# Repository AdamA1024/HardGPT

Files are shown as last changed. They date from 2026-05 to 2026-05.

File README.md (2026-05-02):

# HardGPT

A character-level GPT running entirely on a TI MSPM0G3507 Cortex-M0+ — no host
PC, no network, no accelerator. Press **Generate** and the chip composes
fake-Shakespeare one character at a time on a 16x2 LCD, beeping at the start
and end. Three buttons, three LEDs, an active buzzer, and a dollar's worth of
flash.

The model is a 3-layer transformer (4 heads, 48 embedding dims, block size 48,
65-character vocab) trained on the tiny-shakespeare corpus. Weights are int8
symmetric per-output-channel quantized so the whole network fits in flash, and
the KV cache is also int8 to keep SRAM use sane during generation.

<p align="center">
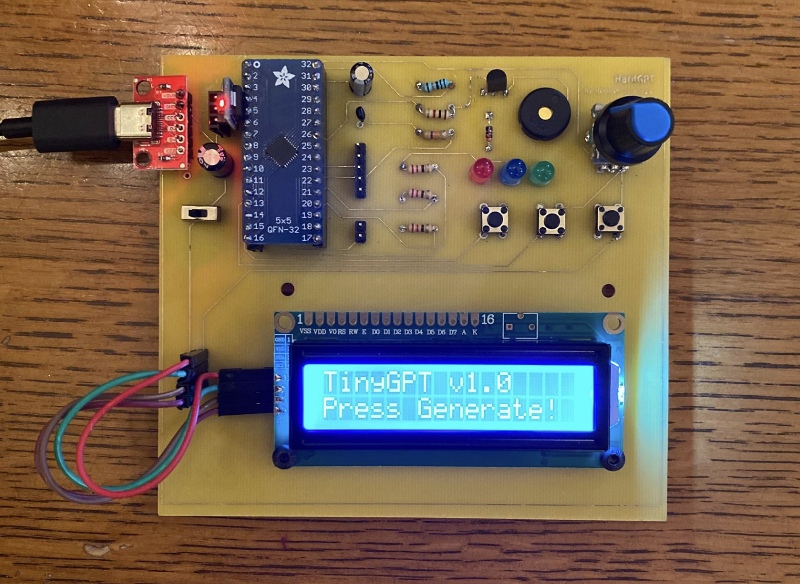
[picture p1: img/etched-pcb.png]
Etched PCB
  
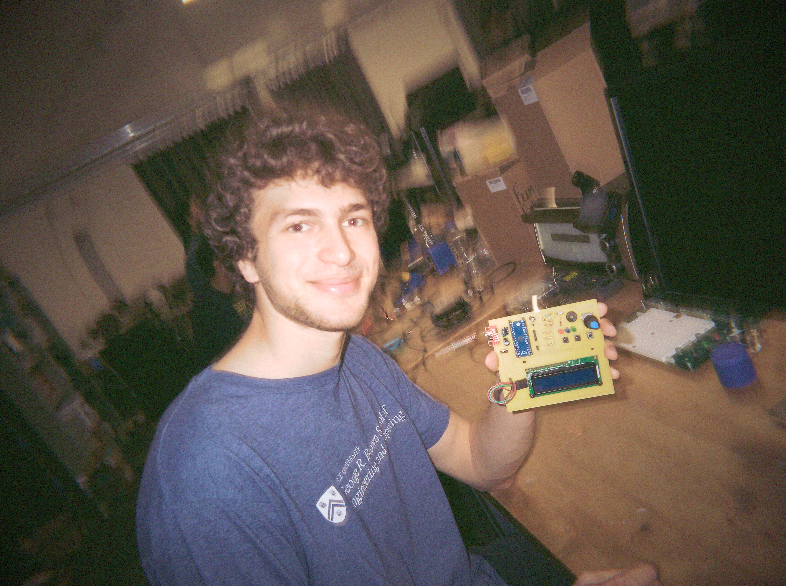
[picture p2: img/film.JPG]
Film
  
</p>

## Repo layout

```
HardGPT/
├── main.c              firmware entry point — UI, transformer inference loop
├── lcd.h               header-only HD44780-via-PCF8574 driver
├── weights.h           int8 weights + vocab, generated by training/export
├── hardgpt.syscfg      sysconfig project: clocks, GPIO, I2C
├── targetConfigs/      CCS debug configs for the launchpad
├── pcb/                kicad project for the board
├── img/                photos used in this readme
└── training/           offline training + weight export pipeline
```

## How it works

The whole firmware lives in a single `main.c` because the model is small
enough that splitting it would just add ceremony. Walking through it top to
bottom:

### Activation and KV-cache buffers

A handful of static SRAM arrays hold the activations of one token at a time:

- `x`, `x_residual`, `x_norm` — the running embedding vector (length `N_EMBD`)
- `qkv` — the combined query/key/value projection (length `3 * N_EMBD`)
- `ffn_hidden` — the 4×-wide MLP hidden state
- `logits` — the output distribution over the 65-character vocabulary
- `x_q` — int8 scratch buffer used whenever we need to quantize an activation

The KV cache is `int8 kv_cache[N_LAYER][BLOCK_SIZE][2 * N_EMBD]` with
`float kv_scales[...]` alongside, so each cached K and V vector keeps its own
quantization scale. Storing it as int8 cuts the cache footprint by ~4× versus
float.

### Math primitives

Everything that touches the hot path uses fast, approximate floats:

- `quantize_vec` — symmetric int8 quantization of a vector with one shared
  scale, used to feed activations into the int8 matmul.
- `matvec_i8i8_pc` — the workhorse. Multiplies an int8 weight matrix (with
  per-row scales) against an int8 activation vector (with one scale) and
  accumulates into int32, then converts to float at the end. This single
  routine handles QKV projection, attention output projection, and both MLP
  matmuls.
- `fast_invsqrt` — the famous Quake `0x5f3759df` trick + one Newton-Raphson
  step. Used by both LayerNorm and the attention scaling factor.
- `fast_expf` — Schraudolph's bit-hack exp. Wildly inaccurate in absolute
  terms but plenty good once softmax normalizes.
- `fast_tanhf` — a Padé approximation, ~1 % error in [-3, 3], used inside
  GELU.
- `layernorm`, `gelu`, `softmax` — built on top of the above.

### The transformer block

`Layer` is just a struct of pointers into `weights.h` so the block code can
work with `L->attn_qkv_w` etc. instead of macro-mangled names.
`init_layers()` wires layer 0/1/2 once at boot.

`block_forward(layer_i, pos)` does one transformer block:

1. Save the residual, layernorm into `x_norm`.
2. Quantize `x_norm`, run the QKV matmul, split into `q`, `k`, `v`.
3. Quantize the new `k` and `v` and store them at `kv_cache[layer_i][pos]`.
4. For each head: dot the head's `q` against every cached `k_t` (dequantizing
   on the fly), scale by `1/sqrt(head_dim)`, softmax, then accumulate the
   weighted sum of cached `v_t`.
5. Quantize the attention output, run the output projection, add the residual.
6. LayerNorm again, run the 4× MLP with GELU, project back, add the residual.

`forward(token_id, pos)` adds the token + position embeddings, calls
`block_forward` for each layer, runs the final LayerNorm, and reuses the
embedding table as the LM head (weight tying) to produce `logits`.

`slide_kv_cache()` shifts the cache left by one when generation runs past
`BLOCK_SIZE`, so the model always sees the most recent `BLOCK_SIZE - 1`
tokens.

### Sampling

Two sampling modes:

- `sample_argmax` — greedy.
- `sample_temp(temperature)` — divide logits by temperature, softmax, draw
  from the distribution using a small linear-congruential RNG.

The probability of the chosen token is stashed in `last_token_prob` so the
"confidence" LED can light up when the model is sure.

### LCD typewriter

`LcdView` holds a 2-row shadow buffer plus the current `(row, col)`. As
characters arrive, `lcd_view_putchar` writes them straight to the LCD and
mirrors them into the shadow buffer. When the cursor walks off row 1, we
copy row 1 up to row 0, blank row 1, and continue — the result is a smooth
typewriter that scrolls upward indefinitely.

### UI / main loop

Boot sequence:

1. `SYSCFG_DL_init()` brings up clocks/GPIO/I2C from sysconfig.
2. `init_layers()` wires the layer pointer table.
3. `lcd_init()` runs the HD44780 wake-up dance and switches it into 4-bit mode.
4. A short buzzer beep confirms power-on.

Then the forever loop:

- **Idle** screen says `HardGPT v1.0 / Press Generate!`. The buttons let you
  cycle through seeds (`Random`, `KING`, `ROMEO`, `LORD`, `HENRY`) or peek at
  the temperature.
- **Generate**: beep, light up the "running" LED, clear the KV cache, print
  the seed name as a cosmetic prefix, then loop:
    - run `forward(token, pos)`
    - sample the next token
    - print it through the LCD typewriter
    - toggle LED 2 (one tick per token), light LED 3 if `last_token_prob > 0.5`
    - increment `pos`; slide the KV cache if we hit `BLOCK_SIZE`
    - bail out early if Generate is pressed again (interrupts the run)
- After 300 tokens (or interrupt), beep twice, wait, and return to idle.

## Hardware

| Peripheral | Pin | Purpose |
|---|---|---|
| 16x2 LCD | I2C0 — SDA on PA0, SCL on PA1 | shows generated text, scrolls upward (PCF8574 backpack)|
| Generate btn  | PA5  (input, internal pull-up) | start / interrupt generation |
| Temp btn | PA7  (input, internal pull-up) | preview the sampling temperature |
| Seed btn | PA8  (input, internal pull-up) | cycle the seed character / name |
| LED 1 | PA12 (output) | "running" — lit during generation |
| LED 2 | PA17 (output) | toggles once per generated token |
| LED 3 | PA18 (output) | lit when sampled token's probability > 0.5 |
| Buzzer | PA22 (output, NPN switch) | boot beep + start/end-of-generation cue |
| SWD | SWCLK on PA20, SWDIO on PA19 | flashing / debug from CCS |

Pin assignments live in `hardgpt.syscfg`; the SDK generates `ti_msp_dl_config.{c,h}`
into `Debug/` from it.

## Training

The model is trained offline using a trimmed-down fork of Andrej Karpathy's
[**nanoGPT**](https://github.com/karpathy/nanoGPT). Pretty much all of the
training code (`model.py`, `train.py`, `sample.py`, `configurator.py`, the
data prep scripts, the overall project structure) is his — go give that repo
a star. The training pipeline lives in `training/` and is a UV-managed Python
project.

```
training/
├── pyproject.toml
├── uv.lock
├── nanoGPT/                  Karpathy's nanoGPT (trimmed to what we use)
│   ├── model.py              GPT model definition
│   ├── train.py              training loop
│   ├── sample.py             inference / sampling reference
│   ├── configurator.py
│   ├── config/train_micro.py our tiny config (3 layers, 48 dims, ...)
│   ├── data/shakespeare_char/ tiny-shakespeare, char-level tokenizer
│   ├── out-micro/ckpt.pt     trained checkpoint
│   ├── LICENSE               nanoGPT MIT license
│   └── README.md             upstream nanoGPT README
├── export/
│   ├── export_weights.py     converts ckpt.pt → weights.h
│   └── weights.h             generated header (also copied into the firmware)
└── inference_c/              desktop C reference impl, used to sanity-check
    ├── main.c                  the on-chip math before flashing
    └── weights.h
```

End-to-end flow:

```
training/nanoGPT/data/shakespeare_char/prepare.py
        │
        ▼     (tokenize)
   train.bin / val.bin
        │
        ▼     (uv run python nanoGPT/train.py config/train_micro.py)
training/nanoGPT/out-micro/ckpt.pt
        │
        ▼     (uv run python export/export_weights.py)
training/export/weights.h ── copied to ──▶ HardGPT/weights.h
                                                   │
                                                   ▼  (CCS build + flash)
                                            on-chip generation
```

`config/train_micro.py` sets the architecture used by the firmware
(`n_layer=3`, `n_head=4`, `n_embd=48`, `block_size=48`, dropout 0.2) and
trains for 30k iterations on `shakespeare_char` with the AdamW recipe nanoGPT
ships with.

`export_weights.py` does symmetric int8 per-output-channel quantization of
every weight matrix, keeps LayerNorm gains as float (they're tiny), and emits
a single `weights.h` containing:

- the architecture `#define`s (`VOCAB_SIZE`, `N_LAYER`, `N_HEAD`, `N_EMBD`,
  `HEAD_DIM`, `BLOCK_SIZE`)
- the character `vocab[]` lookup table
- token / position embeddings + per-row scales
- per-layer attention QKV, attention proj, MLP fc, MLP proj weights and scales
- per-layer LayerNorm gains as float
- the final LayerNorm gain

That header is exactly what `main.c` `#include`s. The on-chip int8 matmul in
`matvec_i8i8_pc` is the dequantization counterpart to what
`export_weights.py` does at quantization time.

### Reproducing

```bash
cd training
uv sync                                       # install torch, numpy, etc.
uv run python nanoGPT/data/shakespeare_char/prepare.py
uv run python nanoGPT/train.py config/train_micro.py
uv run python export/export_weights.py
cp export/weights.h ../weights.h              # firmware picks it up on next build
```

Then build the firmware in CCS (`Project → Clean → Build`) and flash to the
LP-MSPM0G3507.

## Credits

- **Andrej Karpathy** — the entire training stack (`nanoGPT`) is his work,
  used here under its MIT license. See `training/nanoGPT/LICENSE`.
- Tiny-Shakespeare corpus from char-rnn, also via nanoGPT.
- HardGPT firmware (`main.c`, `lcd.h`, `weights.h` packaging, sysconfig, board
  bring-up) is original to this project.

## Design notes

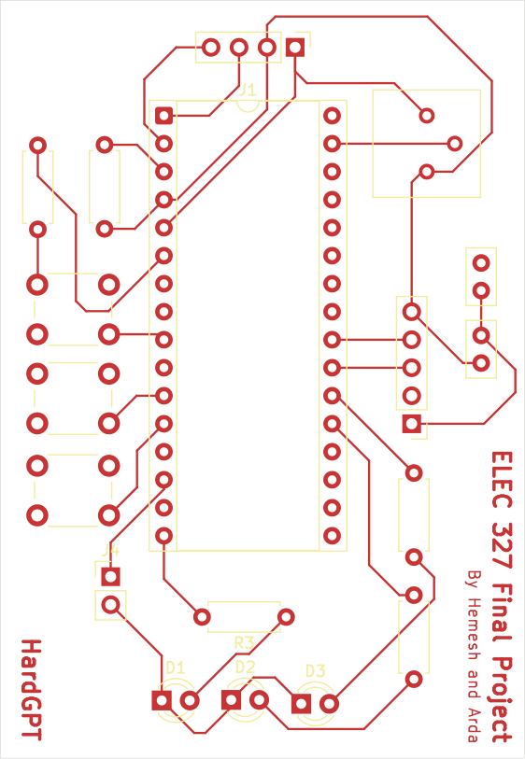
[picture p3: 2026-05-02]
pcb/preview_top.png

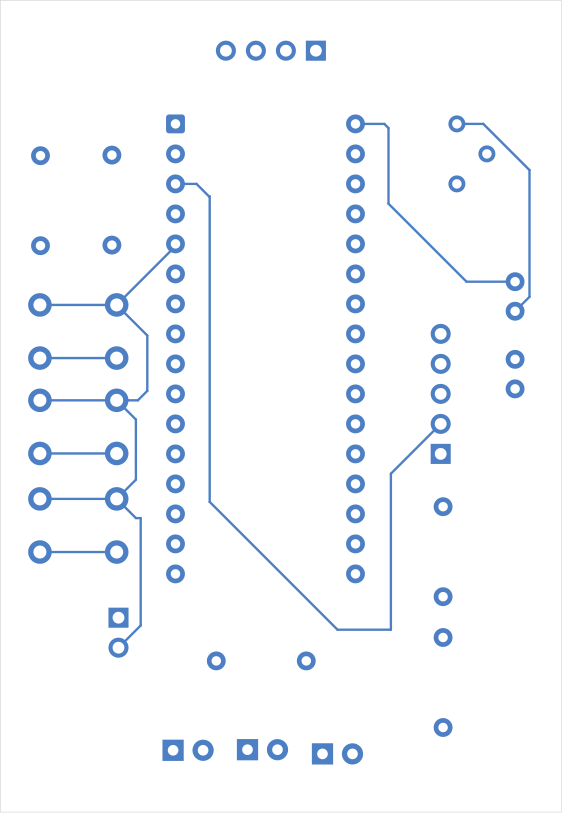
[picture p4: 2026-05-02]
pcb/preview_bottom.png

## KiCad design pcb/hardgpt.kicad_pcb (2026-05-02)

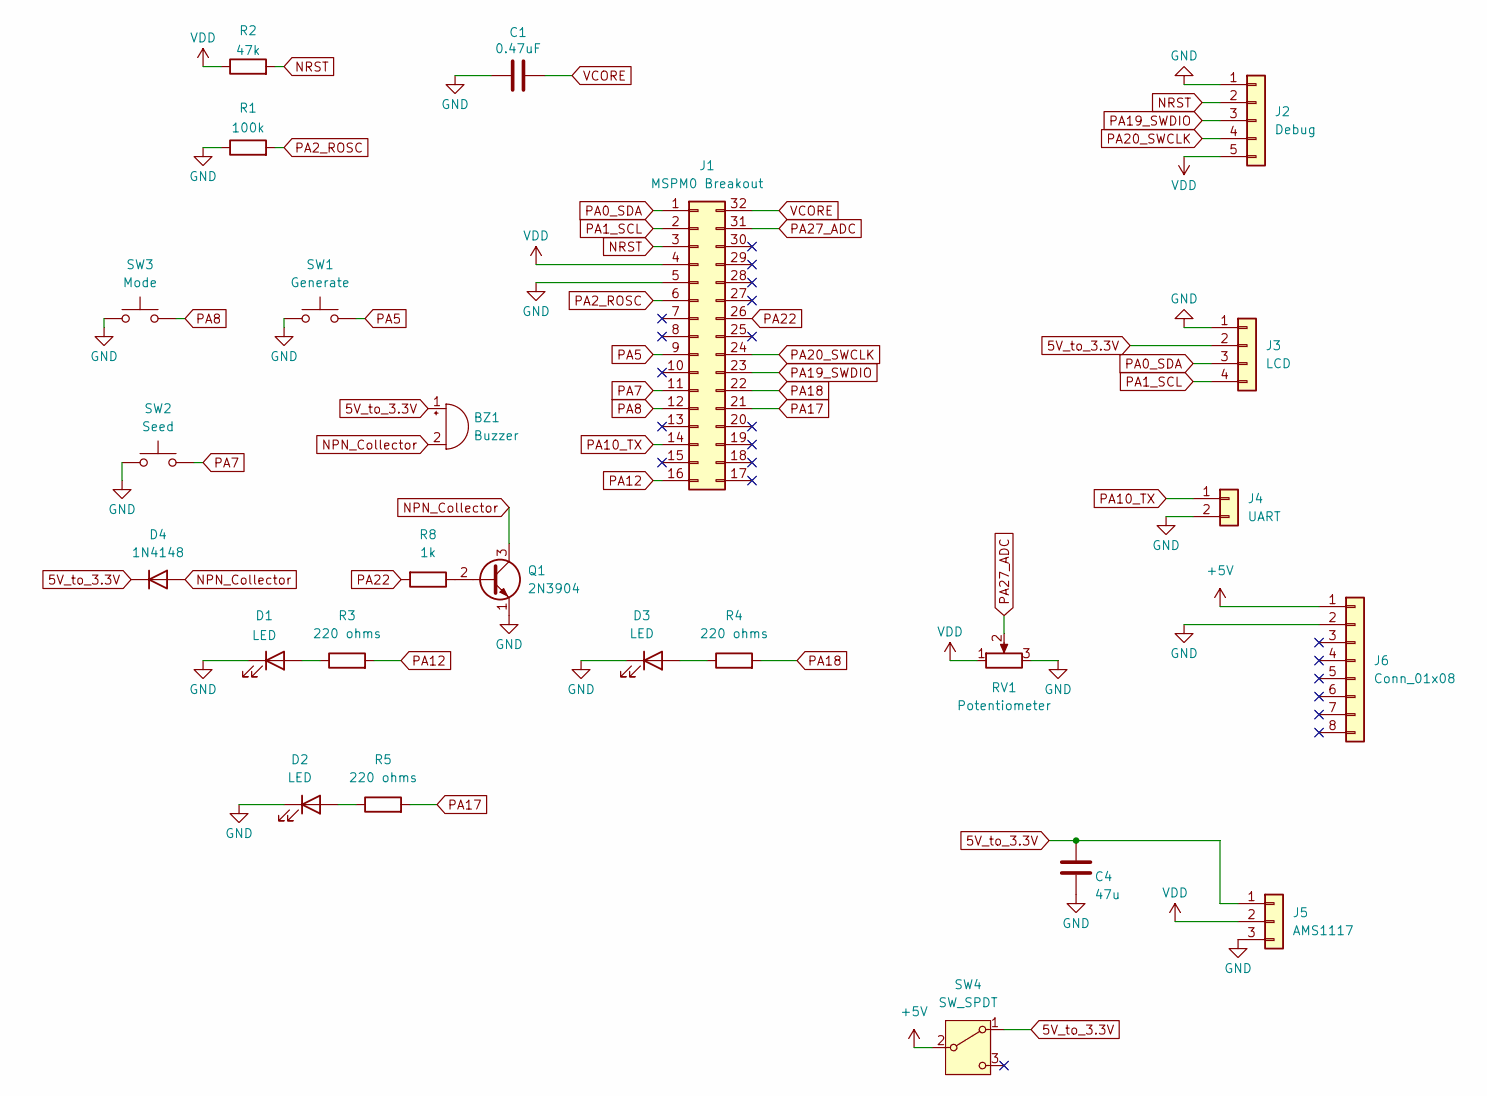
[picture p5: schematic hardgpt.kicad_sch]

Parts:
BZ1: Buzzer; Buzzer_TDK_PS1240P02BT_D12.2mm_H6.5mm
C1: 0.47uF; CP_Radial_D5.0mm_P2.00mm
C4: 47u; CP_Radial_D5.0mm_P2.00mm
D1, D2, D3: LED; LED_D3.0mm
D4: 1N4148; D_DO-35_SOD27_P7.62mm_Horizontal
J1: MSPM0 Breakout; DIP-32_W15.24mm_Socket
J2: Debug; PinHeader_1x05_P2.54mm_Vertical
J3: LCD; PinHeader_1x04_P2.54mm_Vertical
J4: UART; PinHeader_1x02_P2.54mm_Vertical
J5: AMS1117; PinHeader_1x03_P2.54mm_Vertical
J6: Conn_01x08; PinHeader_1x08_P2.54mm_Vertical
Q1: 2N3904; TO-92_Inline_Wide
R1: 100k
R2: 47k
R3, R4, R5: 220 ohms; R_Axial_DIN0207_L6.3mm_D2.5mm_P7.62mm_Horizontal
R8: 1k; R_Axial_DIN0207_L6.3mm_D2.5mm_P7.62mm_Horizontal
RV1: Potentiometer; Potentiometer_Alpha_RD901F-40-00D_Single_Vertical
SW1: Generate; SW_PUSH_6mm
SW2: Seed; SW_PUSH_6mm
SW3: Mode; SW_PUSH_6mm
SW4: SW_SPDT; SW_Slide-03_Wuerth-WS-SLTV_10x2.5x6.4_P2.54mm

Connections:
5V_to_3.3V: BZ1.1 (+), C4.2, D4.1 (K), J3.2, J5.1, SW4.1 (A)
+5V: J6.1, SW4.2 (B)
GND: C1.1, C4.1, D1.1 (K), D2.1 (K), D3.1 (K), J1.5 (GND), J2.1, J3.1, J4.2, J5.3, J6.2, Q1.1 (E), R1.1, RV1.3, SW1.1, SW2.1, SW3.1; also elsewhere on the board
NPN_Collector: BZ1.2 (-), D4.2 (A), Q1.3 (C)
NRST: J1.3 (NRST), J2.2, R2.2
unnamed: D1.2 (A), R3.1
unnamed: D2.2 (A), R5.1
unnamed: D3.2 (A), R4.1
unnamed: Q1.2 (B), R8.1
PA0_SDA: J1.1 (PA0), J3.3
PA1_SCL: J1.2 (PA1), J3.4
PA2_ROSC: J1.6 (PA2), R1.2
PA5: J1.9 (PA5), SW1.2
PA7: J1.11 (PA7), SW2.2
PA8: J1.12 (PA8), SW3.2
PA10_TX: J1.14 (PA10_TX), J4.1
PA12: J1.16 (PA12), R3.2
PA17: J1.21 (PA17), R5.2
PA18: J1.22 (PA18), R4.2
PA19_SWDIO: J1.23 (PA19_SWDIO), J2.3
PA20_SWCLK: J1.24 (PA20_SWCLK), J2.4
PA22: J1.26 (PA22), R8.2
PA27_ADC: J1.31 (PA27), RV1.2
VCORE: C1.2, J1.32 (VCORE)
VDD: J1.4 (VDD), J2.5, J5.2, R2.1, RV1.1; also elsewhere on the board

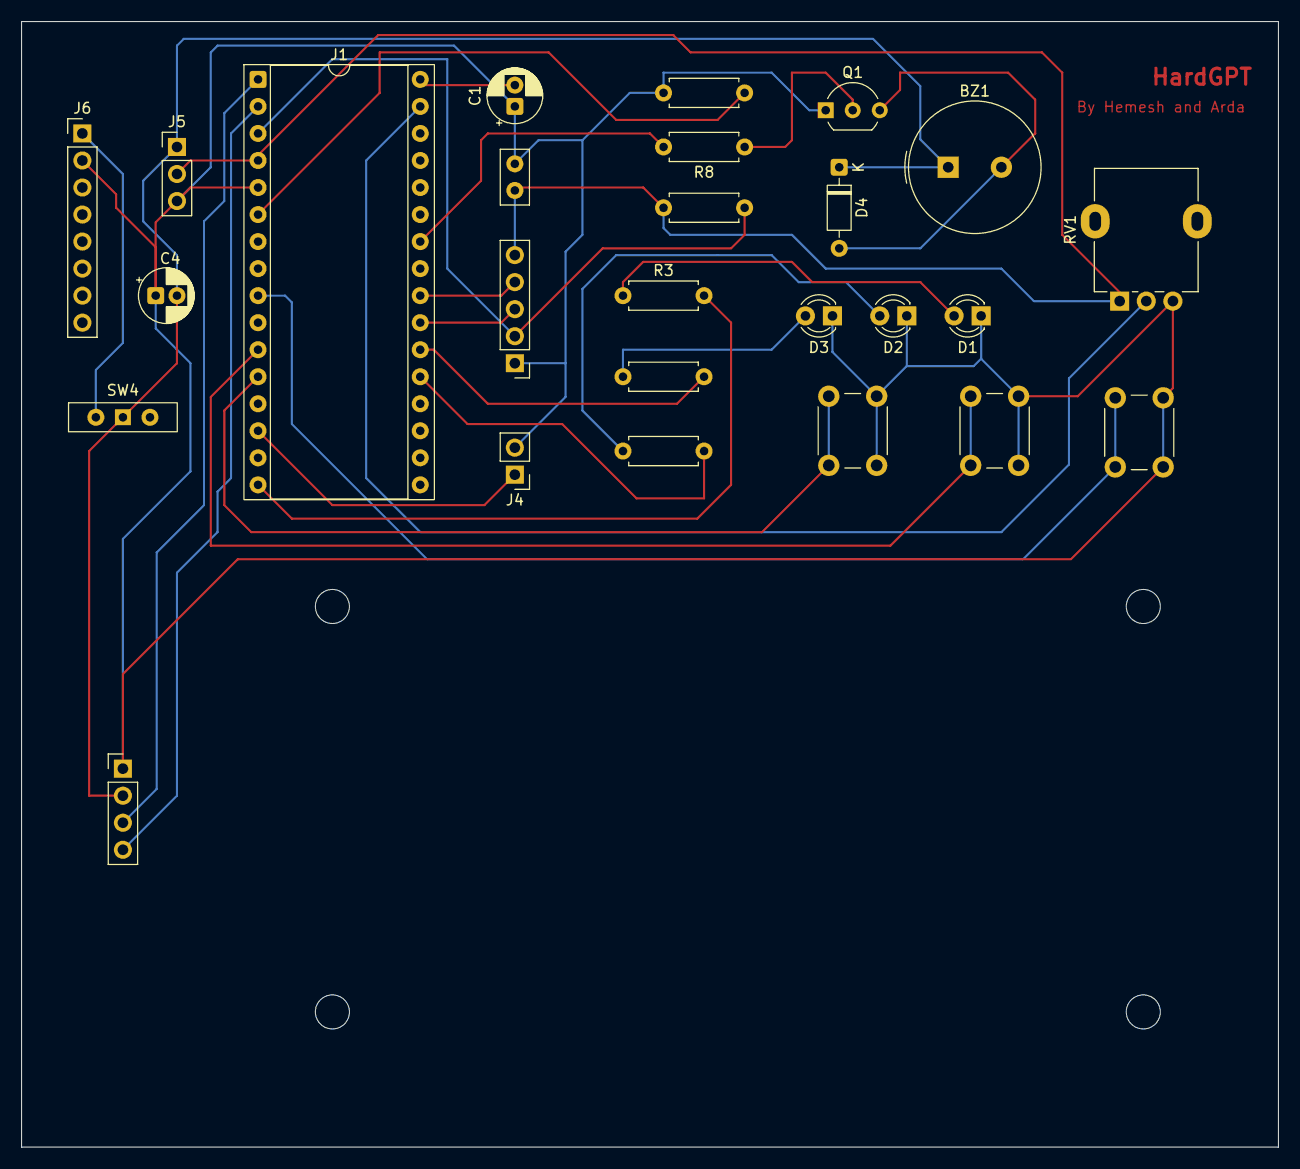
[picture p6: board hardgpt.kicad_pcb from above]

Board: 2 copper layers, 118.1 x 105.8 mm, 26 parts (0 on the bottom side), 25 nets.

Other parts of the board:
C2: 0.1uF; C_Disc_D5.0mm_W2.5mm_P2.50mm

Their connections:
GND: C2.2; also elsewhere on the board
VDD: C2.1; also elsewhere on the board

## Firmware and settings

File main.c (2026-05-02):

/*
 * hardgpt on the mspm0g3507 - a tiny character-level transformer running
 * on-chip. weights are int8 quantized and we keep an int8 kv cache so it
 * actually fits in sram. peripherals: 16x2 i2c lcd, three buttons
 * (generate / temp / seed), three status leds, and an active buzzer
 * driven through an npn transistor.
 */
 
#include "ti_msp_dl_config.h"
#include "weights.h"
#include "lcd.h"
#include <stdint.h>
#include <string.h>

#define FFN_DIM            (4 * N_EMBD)
#define MAX_GENERATE       300
#define FIXED_TEMPERATURE  0.8f

/* activation scratch buffers — live in sram, reused every step */
static float  x[N_EMBD];
static float  x_residual[N_EMBD];
static float  x_norm[N_EMBD];
static float  qkv[3 * N_EMBD];
static float  ffn_hidden[FFN_DIM];
static float  logits[VOCAB_SIZE];
static int8_t x_q[FFN_DIM];

/* kv cache stored as int8 with one scale per (layer, position) for k and v */
static int8_t kv_cache[N_LAYER][BLOCK_SIZE][2 * N_EMBD];
static float  kv_scales[N_LAYER][BLOCK_SIZE][2];
static float  attn_scores[BLOCK_SIZE];

/* probability of the most recently sampled token - drives the confidence led */
static float last_token_prob = 0.0f;

/* crude busy-wait. good enough for the human-scale delays we need here. */
static void delay_nops(uint32_t n) {
    volatile uint32_t d = n;
    while (d--) { __asm__("nop"); }
}

/* per-vector symmetric int8 quantization. returns the scale used. */
static float quantize_vec(const float *in, int8_t *out, int n) {
    float max_abs = 0.0f;
    for (int i = 0; i < n; i++) {
        float a = in[i] < 0 ? -in[i] : in[i];
        if (a > max_abs) max_abs = a;
    }
    if (max_abs == 0.0f) {
        for (int i = 0; i < n; i++) out[i] = 0;
        return 1.0f;
    }
    float scale = max_abs * (1.0f / 127.0f);
    float inv_scale = 1.0f / scale;
    for (int i = 0; i < n; i++) {
        int v = (int)(in[i] * inv_scale + (in[i] >= 0 ? 0.5f : -0.5f));
        if (v > 127) v = 127;
        if (v < -127) v = -127;
        out[i] = (int8_t)v;
    }
    return scale;
}

static void matvec_i8i8_pc(
    const int8_t *W, const float *W_scales,
    const int8_t *in, float in_scale,
    float *out,
    int out_dim, int in_dim)
{
    for (int o = 0; o < out_dim; o++) {
        int32_t acc = 0;
        const int8_t *row = W + o * in_dim;
        for (int i = 0; i < in_dim; i++) {
            acc += (int32_t)row[i] * (int32_t)in[i];
        }
        out[o] = (float)acc * W_scales[o] * in_scale;
    }
}

/* the famous quake 1/sqrt(x) trick, one newton-raphson pass for accuracy */
static float fast_invsqrt(float x) {
    float xhalf = 0.5f * x;
    int32_t i;
    memcpy(&i, &x, 4);
    i = 0x5f3759df - (i >> 1);
    memcpy(&x, &i, 4);
    x *= (1.5f - xhalf * x * x);
    return x;
}

/* schraudolph's bit-hack exp. plenty accurate once softmax normalizes it. */
static float fast_expf(float x) {
    if (x < -87.0f) return 0.0f;
    if (x >  88.0f) return 3.4e38f;
    union { float f; int32_t i; } u;
    u.i = (int32_t)(12102203.0f * x + 1064866805.0f);
    return u.f;
}

/* padé approximation of tanh — about 1% off in [-3, 3], dirt cheap */
static float fast_tanhf(float x) {
    if (x <= -3.0f) return -1.0f;
    if (x >=  3.0f) return  1.0f;
    float x2 = x * x;
    return x * (27.0f + x2) / (27.0f + 9.0f * x2);
}

static void layernorm(float *out, const float *in, const float *weight, int dim) {
    float mean = 0.0f;
    for (int i = 0; i < dim; i++) mean += in[i];
    mean /= (float)dim;
    float var = 0.0f;
    for (int i = 0; i < dim; i++) {
        float d = in[i] - mean;
        var += d * d;
    }
    var /= (float)dim;
    float inv_std = fast_invsqrt(var + 1e-5f);
    for (int i = 0; i < dim; i++) {
        out[i] = (in[i] - mean) * inv_std * weight[i];
    }
}

static inline float gelu(float v) {
    const float c = 0.7978845608f;
    return 0.5f * v * (1.0f + fast_tanhf(c * (v + 0.044715f * v * v * v)));
}

static void softmax(float *v, int n) {
    float max = v[0];
    for (int i = 1; i < n; i++) if (v[i] > max) max = v[i];
    float sum = 0.0f;
    for (int i = 0; i < n; i++) {
        v[i] = fast_expf(v[i] - max);
        sum += v[i];
    }
    float inv_sum = 1.0f / sum;
    for (int i = 0; i < n; i++) v[i] *= inv_sum;
}

/* a layer's worth of pointers into the giant weights table */
typedef struct {
    const float  *ln1_w;
    const int8_t *attn_qkv_w;  const float *attn_qkv_scales;
    const int8_t *attn_proj_w; const float *attn_proj_scales;
    const float  *ln2_w;
    const int8_t *mlp_fc_w;    const float *mlp_fc_scales;
    const int8_t *mlp_proj_w;  const float *mlp_proj_scales;
} Layer;

static Layer layers[N_LAYER];

static void init_layers(void) {
    layers[0].ln1_w = ln1_w_0;
    layers[0].attn_qkv_w  = attn_qkv_w_0;  layers[0].attn_qkv_scales  = attn_qkv_w_0_scales;
    layers[0].attn_proj_w = attn_proj_w_0; layers[0].attn_proj_scales = attn_proj_w_0_scales;
    layers[0].ln2_w = ln2_w_0;
    layers[0].mlp_fc_w    = mlp_fc_w_0;    layers[0].mlp_fc_scales    = mlp_fc_w_0_scales;
    layers[0].mlp_proj_w  = mlp_proj_w_0;  layers[0].mlp_proj_scales  = mlp_proj_w_0_scales;

    layers[1].ln1_w = ln1_w_1;
    layers[1].attn_qkv_w  = attn_qkv_w_1;  layers[1].attn_qkv_scales  = attn_qkv_w_1_scales;
    layers[1].attn_proj_w = attn_proj_w_1; layers[1].attn_proj_scales = attn_proj_w_1_scales;
    layers[1].ln2_w = ln2_w_1;
    layers[1].mlp_fc_w    = mlp_fc_w_1;    layers[1].mlp_fc_scales    = mlp_fc_w_1_scales;
    layers[1].mlp_proj_w  = mlp_proj_w_1;  layers[1].mlp_proj_scales  = mlp_proj_w_1_scales;

    layers[2].ln1_w = ln1_w_2;
    layers[2].attn_qkv_w  = attn_qkv_w_2;  layers[2].attn_qkv_scales  = attn_qkv_w_2_scales;
    layers[2].attn_proj_w = attn_proj_w_2; layers[2].attn_proj_scales = attn_proj_w_2_scales;
    layers[2].ln2_w = ln2_w_2;
    layers[2].mlp_fc_w    = mlp_fc_w_2;    layers[2].mlp_fc_scales    = mlp_fc_w_2_scales;
    layers[2].mlp_proj_w  = mlp_proj_w_2;  layers[2].mlp_proj_scales  = mlp_proj_w_2_scales;
}

static void block_forward(int layer_i, int pos) {
    Layer *L = &layers[layer_i];

    /* self-attention block: layernorm, project to q/k/v, attend, project out */
    memcpy(x_residual, x, sizeof(x));
    layernorm(x_norm, x, L->ln1_w, N_EMBD);

    float in_scale = quantize_vec(x_norm, x_q, N_EMBD);
    matvec_i8i8_pc(L->attn_qkv_w, L->attn_qkv_scales, x_q, in_scale,
                   qkv, 3 * N_EMBD, N_EMBD);

    float *q = qkv;
    float *k = qkv + N_EMBD;
    float *v = qkv + 2 * N_EMBD;

    /* stash the new k and v for this position, quantized down to int8 */
    int8_t *k_dst = &kv_cache[layer_i][pos][0];
    int8_t *v_dst = &kv_cache[layer_i][pos][N_EMBD];
    kv_scales[layer_i][pos][0] = quantize_vec(k, k_dst, N_EMBD);
    kv_scales[layer_i][pos][1] = quantize_vec(v, v_dst, N_EMBD);

    float attn_out[N_EMBD] = {0};
    float attn_scale = fast_invsqrt((float)HEAD_DIM);

    for (int h = 0; h < N_HEAD; h++) {
        float *q_h = q + h * HEAD_DIM;
        for (int t = 0; t <= pos; t++) {
            const int8_t *k_t = &kv_cache[layer_i][t][h * HEAD_DIM];
            float k_scale = kv_scales[layer_i][t][0];
            float dot = 0.0f;
            for (int i = 0; i < HEAD_DIM; i++) {
                dot += q_h[i] * ((float)k_t[i] * k_scale);
            }
            attn_scores[t] = dot * attn_scale;
        }
        softmax(attn_scores, pos + 1);
        for (int t = 0; t <= pos; t++) {
            const int8_t *v_t = &kv_cache[layer_i][t][N_EMBD + h * HEAD_DIM];
            float v_scale = kv_scales[layer_i][t][1];
            float w = attn_scores[t];
            for (int i = 0; i < HEAD_DIM; i++) {
                attn_out[h * HEAD_DIM + i] += w * ((float)v_t[i] * v_scale);
            }
        }
    }

    float attn_proj_out[N_EMBD];
    in_scale = quantize_vec(attn_out, x_q, N_EMBD);
    matvec_i8i8_pc(L->attn_proj_w, L->attn_proj_scales, x_q, in_scale,
                   attn_proj_out, N_EMBD, N_EMBD);

    for (int i = 0; i < N_EMBD; i++) x[i] = x_residual[i] + attn_proj_out[i];

    /* feed-forward block: layernorm, expand 4x with gelu, project back */
    memcpy(x_residual, x, sizeof(x));
    layernorm(x_norm, x, L->ln2_w, N_EMBD);

    in_scale = quantize_vec(x_norm, x_q, N_EMBD);
    matvec_i8i8_pc(L->mlp_fc_w, L->mlp_fc_scales, x_q, in_scale,
                   ffn_hidden, FFN_DIM, N_EMBD);

    for (int i = 0; i < FFN_DIM; i++) ffn_hidden[i] = gelu(ffn_hidden[i]);

    float ffn_proj_out[N_EMBD];
    in_scale = quantize_vec(ffn_hidden, x_q, FFN_DIM);
    matvec_i8i8_pc(L->mlp_proj_w, L->mlp_proj_scales, x_q, in_scale,
                   ffn_proj_out, N_EMBD, FFN_DIM);

    for (int i = 0; i < N_EMBD; i++) x[i] = x_residual[i] + ffn_proj_out[i];
}

static void forward(int token_id, int pos) {
    for (int i = 0; i < N_EMBD; i++) {
        x[i] = (float)wte[token_id * N_EMBD + i] * wte_scales[token_id]
             + (float)wpe[pos       * N_EMBD + i] * wpe_scales[pos];
    }
    for (int l = 0; l < N_LAYER; l++) block_forward(l, pos);
    layernorm(x_norm, x, lnf_w, N_EMBD);

    float lm_in_scale = quantize_vec(x_norm, x_q, N_EMBD);
    matvec_i8i8_pc(wte, wte_scales, x_q, lm_in_scale,
                   logits, VOCAB_SIZE, N_EMBD);
}

static void slide_kv_cache(void) {
    for (int l = 0; l < N_LAYER; l++) {
        for (int t = 0; t < BLOCK_SIZE - 1; t++) {
            for (int i = 0; i < 2 * N_EMBD; i++) {
                kv_cache[l][t][i] = kv_cache[l][t + 1][i];
            }
            kv_scales[l][t][0] = kv_scales[l][t + 1][0];
            kv_scales[l][t][1] = kv_scales[l][t + 1][1];
        }
    }
}

/* greedy pick — always take the highest-logit token */
static int sample_argmax(void) {
    int best = 0;
    for (int i = 1; i < VOCAB_SIZE; i++)
        if (logits[i] > logits[best]) best = i;
    last_token_prob = 1.0f;
    return best;
}

/* tiny linear-congruential rng — seedable from button presses */
static uint32_t rng_state = 12345;
static float rand_unit(void) {
    rng_state = rng_state * 1664525u + 1013904223u;
    return (float)(rng_state >> 8) / (float)(1u << 24);
}

static int sample_temp(float temperature) {
    if (temperature <= 0.0f) return sample_argmax();
    float inv_temp = 1.0f / temperature;
    for (int i = 0; i < VOCAB_SIZE; i++) logits[i] *= inv_temp;
    softmax(logits, VOCAB_SIZE);
    float r = rand_unit();
    float cum = 0.0f;
    for (int i = 0; i < VOCAB_SIZE; i++) {
        cum += logits[i];
        if (r < cum) {
            last_token_prob = logits[i];
            return i;
        }
    }
    last_token_prob = logits[VOCAB_SIZE - 1];
    return VOCAB_SIZE - 1;
}

/* buttons are active-low — pull-ups are configured in sysconfig */
static int btn_pressed(uint32_t pin_mask) {
    return !(DL_GPIO_readPins(GPIO_BUTTONS_PORT, pin_mask) & pin_mask);
}
static int btn_generate(void) { return btn_pressed(GPIO_BUTTONS_GENERATE_PIN); }
static int btn_temp(void)     { return btn_pressed(GPIO_BUTTONS_TEMP_PIN); }
static int btn_seed(void)     { return btn_pressed(GPIO_BUTTONS_SEED_PIN); }

/* spin until the user lets go of every button, plus a small debounce pause */
static void wait_release(void) {
    while (btn_generate() || btn_temp() || btn_seed()) { }
    delay_nops(200000);
}

/* active buzzer wired to pa22 through an npn switch — pin high turns it on */
static void buzzer_beep(uint32_t nops) {
    DL_GPIO_setPins(GPIO_BUZZER_PORT, GPIO_BUZZER_BUZZER_PIN);
    delay_nops(nops);
    DL_GPIO_clearPins(GPIO_BUZZER_PORT, GPIO_BUZZER_BUZZER_PIN);
}

static void leds_clear_all(void) {
    DL_GPIO_clearPins(GPIO_LEDS_PORT,
        GPIO_LEDS_USER_LED_1_PIN |
        GPIO_LEDS_USER_LED_2_PIN |
        GPIO_LEDS_USER_LED_3_PIN);
}

/* tiny "typewriter" wrapper around the lcd: tracks a 2-row shadow buffer
 * so we can scroll up when generation overflows the second row */
typedef struct {
    int  row;
    int  col;
    char line0[17];
    char line1[17];
} LcdView;

static void lcd_view_reset(LcdView *v) {
    v->row = 0;
    v->col = 0;
    memset(v->line0, 0, sizeof(v->line0));
    memset(v->line1, 0, sizeof(v->line1));
}

static void lcd_scroll_up(LcdView *v) {
    memcpy(v->line0, v->line1, 16);
    memset(v->line1, ' ', 16);
    v->line0[16] = 0;
    lcd_set_cursor(0, 0);
    lcd_puts(v->line0);
    lcd_set_cursor(1, 0);
    lcd_puts("                ");
    lcd_set_cursor(1, 0);
    v->col = 0;
}

static void lcd_advance_line(LcdView *v) {
    if (v->row == 0) {
        v->row = 1;
        v->col = 0;
        lcd_set_cursor(1, 0);
    } else {
        lcd_scroll_up(v);
    }
}

static void lcd_view_putchar(LcdView *v, char c) {
    if (c == '\n') {
        lcd_advance_line(v);
        return;
    }
    if (v->col >= 16) lcd_advance_line(v);
    char *target = (v->row == 0) ? v->line0 : v->line1;
    target[v->col] = c;
    lcd_putchar(c);
    v->col++;
}

static void lcd_view_puts(LcdView *v, const char *s) {
    while (*s) lcd_view_putchar(v, *s++);
}

/* seed options shown on the lcd. the first one feeds a newline so the model
 * starts a fresh utterance; the rest prime it with a shakespeare character. */
static const char        seed_chars[] = {'\n', 'K',  'R',     'L',    'H'    };
static const char *const seed_names[] = {"Random", "KING", "ROMEO", "LORD", "HENRY"};
#define NUM_SEEDS (sizeof(seed_chars) / sizeof(seed_chars[0]))

static void show_idle_screen(void) {
    lcd_clear();
    lcd_puts("HardGPT v1.0");
    lcd_set_cursor(1, 0);
    lcd_puts("Press Generate!");
}

static void show_seed_screen(int seed_idx) {
    lcd_clear();
    lcd_puts("Seed:");
    lcd_set_cursor(1, 0);
    lcd_puts(seed_names[seed_idx]);
}

static void show_temp_screen(float temp) {
    int whole = (int)temp;
    int frac  = (int)((temp - (float)whole) * 100.0f);
    if (frac < 0) frac = -frac;
    char tbuf[6];
    tbuf[0] = '0' + whole;
    tbuf[1] = '.';
    tbuf[2] = '0' + (frac / 10);
    tbuf[3] = '0' + (frac % 10);
    tbuf[4] = 0;

    lcd_clear();
    lcd_puts("Temperature:");
    lcd_set_cursor(1, 0);
    lcd_puts(tbuf);
}

/* look up the vocab index for a seed char; falls back to index 0 if missing */
static int seed_token_id(char seed_char) {
    for (int i = 0; i < VOCAB_SIZE; i++) {
        if (vocab[i] == seed_char) return i;
    }
    return 0;
}

int main(void)
{
    SYSCFG_DL_init();
    init_layers();
    lcd_init();

    /* short beep on boot so we know the board woke up */
    buzzer_beep(2400000);

    int seed_idx = 0;

    while (1) {
        /* idle: show the title and wait for input */
        show_idle_screen();
        leds_clear_all();

        for (;;) {
            if (btn_seed()) {
                seed_idx = (seed_idx + 1) % NUM_SEEDS;
                show_seed_screen(seed_idx);
                wait_release();
                delay_nops(2000000);
                show_idle_screen();
            }

            if (btn_temp()) {
                show_temp_screen(FIXED_TEMPERATURE);
                wait_release();
                delay_nops(1500000);
                show_idle_screen();
            }

            if (btn_generate()) {
                wait_release();
                break;
            }
        }

        /* generate: kick off a beep and start streaming tokens to the lcd */
        buzzer_beep(1600000);
        DL_GPIO_setPins(GPIO_LEDS_PORT, GPIO_LEDS_USER_LED_1_PIN);

        int token_id = seed_token_id(seed_chars[seed_idx]);
        int pos = 0;
        int generated = 0;
        int interrupted = 0;

        memset(kv_cache, 0, sizeof(kv_cache));
        memset(kv_scales, 0, sizeof(kv_scales));

        LcdView view;
        lcd_view_reset(&view);
        lcd_clear();

        /* purely cosmetic — print the seed name as a prefix; the model never sees it */
        lcd_view_puts(&view, seed_names[seed_idx]);
        lcd_view_putchar(&view, ':');
        lcd_view_putchar(&view, ' ');

        while (generated < MAX_GENERATE && !interrupted) {
            forward(token_id, pos);
            token_id = sample_temp(FIXED_TEMPERATURE);

            lcd_view_putchar(&view, vocab[token_id]);

            DL_GPIO_togglePins(GPIO_LEDS_PORT, GPIO_LEDS_USER_LED_2_PIN);
            if (last_token_prob > 0.5f)
                DL_GPIO_setPins(GPIO_LEDS_PORT, GPIO_LEDS_USER_LED_3_PIN);
            else
                DL_GPIO_clearPins(GPIO_LEDS_PORT, GPIO_LEDS_USER_LED_3_PIN);

            pos++;
            generated++;

            if (pos >= BLOCK_SIZE) {
                slide_kv_cache();
                pos = BLOCK_SIZE - 1;
            }

            if (btn_generate()) {
                interrupted = 1;
                wait_release();
            }
        }

        leds_clear_all();

        if (!interrupted) {
            buzzer_beep(1600000);
            delay_nops(1000000);
            buzzer_beep(1600000);
            delay_nops(8000000);
        }
    }
}

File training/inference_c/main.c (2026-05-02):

/*
 * Tiny GPT inference engine — pure portable C, float math.
 * Phase 1: get the architecture right with floats.
 * Phase 2 (later): swap matmuls for fixed-point int8.
 *
 * Compile: clang -O2 -o tinygpt main.c -lm
 * Run:     ./tinygpt
 */

#include <stdio.h>
#include <stdlib.h>
#include <string.h>
#include <stdint.h>
#include <math.h>
#include <time.h>

#include "weights.h"
#define FFN_DIM (4 * N_EMBD)   // nanoGPT MLP hidden dim is 4 * n_embd

/* ============================================================
 * Activation buffers — these would live in SRAM on the MCU.
 * Keep them as globals so we can see the total footprint.
 * ============================================================ */
static float x[N_EMBD];                    // current token embedding
static float x_residual[N_EMBD];           // residual stream backup
static float x_norm[N_EMBD];               // post-layernorm
static float qkv[3 * N_EMBD];              // Q, K, V concatenated for current token
static float ffn_hidden[FFN_DIM];          // FFN intermediate
static float logits[VOCAB_SIZE];
static int8_t x_q[FFN_DIM];   // largest activation we'll quantize is FFN hidden

// KV cache: [layer][position][head][k_or_v][head_dim]
// Flattened: [N_LAYER][BLOCK_SIZE][2 * N_EMBD]
static float kv_cache[N_LAYER][BLOCK_SIZE][2 * N_EMBD];

// Attention scratch
static float attn_scores[BLOCK_SIZE];

/* ============================================================
 * Helpers: dequantize int8 weight to float on the fly.
 * Later we replace this with int8 MAC accumulation.
 * ============================================================ */
static inline float dq(int8_t q, float scale) {
    return (float)q * scale;
}

/* ============================================================
 * Quantize a float vector to int8 symmetric, returning the scale.
 * ============================================================ */
static float quantize_vec(const float *in, int8_t *out, int n) {
    float max_abs = 0.0f;
    for (int i = 0; i < n; i++) {
        float a = fabsf(in[i]);
        if (a > max_abs) max_abs = a;
    }
    if (max_abs == 0.0f) {
        for (int i = 0; i < n; i++) out[i] = 0;
        return 1.0f;
    }
    float scale = max_abs / 127.0f;
    float inv_scale = 1.0f / scale;
    for (int i = 0; i < n; i++) {
        int v = (int)lrintf(in[i] * inv_scale);
        if (v > 127) v = 127;
        if (v < -127) v = -127;
        out[i] = (int8_t)v;
    }
    return scale;
}

/* ============================================================
 * True int8 x int8 -> int32 matvec.
 *   W is row-major (out_dim, in_dim), int8, scale W_scale
 *   in is int8[in_dim], scale in_scale
 *   out is float[out_dim]
 * Output is computed as: out[o] = (W_scale * in_scale) * sum(W[o,i] * in[i])
 * The sum runs entirely in int32. Only the final multiply touches float.
 * ============================================================ */
static void matvec_i8i8_pc(
    const int8_t *W, const float *W_scales,
    const int8_t *in, float in_scale,
    float *out,
    int out_dim, int in_dim)
{
    for (int o = 0; o < out_dim; o++) {
        int32_t acc = 0;
        const int8_t *row = W + o * in_dim;
        for (int i = 0; i < in_dim; i++) {
            acc += (int32_t)row[i] * (int32_t)in[i];
        }
        out[o] = (float)acc * W_scales[o] * in_scale;
    }
}

/* ============================================================
 * RMS-style layernorm (nanoGPT uses LayerNorm without bias when bias=False)
 * Standard LayerNorm: y = (x - mean) / sqrt(var + eps) * weight
 * ============================================================ */
/* ---- Fast math approximations (match MCU build) ---- */

static float fast_invsqrt(float x) {
    float xhalf = 0.5f * x;
    int32_t i;
    memcpy(&i, &x, 4);
    i = 0x5f3759df - (i >> 1);
    memcpy(&x, &i, 4);
    x *= (1.5f - xhalf * x * x);
    return x;
}

static float fast_expf(float x) {
    if (x < -87.0f) return 0.0f;
    if (x >  88.0f) return 3.4e38f;
    union { float f; int32_t i; } u;
    u.i = (int32_t)(12102203.0f * x + 1064866805.0f);
    return u.f;
}

static float fast_tanhf(float x) {
    if (x <= -3.0f) return -1.0f;
    if (x >=  3.0f) return  1.0f;
    float x2 = x * x;
    return x * (27.0f + x2) / (27.0f + 9.0f * x2);
}

static void layernorm(float *out, const float *in, const float *weight, int dim) {
    float mean = 0.0f;
    for (int i = 0; i < dim; i++) mean += in[i];
    mean /= (float)dim;

    float var = 0.0f;
    for (int i = 0; i < dim; i++) {
        float d = in[i] - mean;
        var += d * d;
    }
    var /= (float)dim;

    float inv_std = fast_invsqrt(var + 1e-5f);
    for (int i = 0; i < dim; i++) {
        out[i] = (in[i] - mean) * inv_std * weight[i];
    }
}

/* ============================================================
 * GELU activation (nanoGPT uses approximate GELU)
 * tanh approximation: 0.5 * x * (1 + tanh(sqrt(2/pi) * (x + 0.044715 * x^3)))
 * ============================================================ */
static inline float gelu(float x) {
    const float c = 0.7978845608f; // sqrt(2/pi)
    return 0.5f * x * (1.0f + fast_tanhf(c * (x + 0.044715f * x * x * x)));
}

/* ============================================================
 * Softmax in-place over a length-n array
 * ============================================================ */
static void softmax(float *x, int n) {
    float max = x[0];
    for (int i = 1; i < n; i++) if (x[i] > max) max = x[i];
    float sum = 0.0f;
    for (int i = 0; i < n; i++) {
        x[i] = fast_expf(x[i] - max);
        sum += x[i];
    }
    float inv_sum = 1.0f / sum;
    for (int i = 0; i < n; i++) x[i] *= inv_sum;
}

/* ============================================================
 * Per-layer weight pointers (built from weights.h symbols)
 * ============================================================ */
typedef struct {
    const float *ln1_w;
    const int8_t *attn_qkv_w;  const float *attn_qkv_scales;
    const int8_t *attn_proj_w; const float *attn_proj_scales;
    const float *ln2_w;
    const int8_t *mlp_fc_w;    const float *mlp_fc_scales;
    const int8_t *mlp_proj_w;  const float *mlp_proj_scales;
} Layer;

static Layer layers[N_LAYER];
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

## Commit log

2026-05-02 initial commit
    hardgpt firmware and training pipeline. mspm0g3507 character-level
    transformer with int8-quantized weights, kv cache, and a minimal lcd,
    button, led, and buzzer ui. training pipeline is a trimmed fork of
    karpathy's nanogpt plus an int8 weight exporter.
    [main.c]
2026-05-02 add pcb design
    kicad project for the hardgpt board, plus rendered top and bottom
    previews. dropped autobackups, drc reports, and the footprint info
    cache from the upstream folder dump.
    [hardgpt.kicad_pcb, hardgpt.kicad_sch]
2026-05-02 add etched pcb and film photos to readme
2026-05-02 reorder readme and document pcb in repo layout
